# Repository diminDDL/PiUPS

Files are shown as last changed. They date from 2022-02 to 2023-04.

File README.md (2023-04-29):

# The DDL pi UPS


# Terms of use
### The following conditions should be met if you want to use any part of this repository:

By using this project or its parts, for any purpose and in any shape or form, you grant your **implicit agreement** to all the following statements:

- You **condemn Russia and its military aggression against Ukraine**
- You **recognize that Russia is an occupant that unlawfully invaded a sovereign state**
- You **support Ukraine's territorial integrity, including its claims over temporarily occupied territories of Crimea and Donbas**
- You **reject false narratives perpetuated by Russian state propaganda**

To learn more about the war and how you can help, [click here](https://u24.gov.ua/). Glory to Ukraine! 🇺🇦

### AND

## CERN Open Hardware Licence v2 (CERN-OHL-W) TL;DR

- **Can:**
  - *Use*: You are free to use the hardware design in any way.
  - *Modify*: You can make modifications to the design.
  - *Distribute*: You can share the original or modified design with others.
  - *Commercial Use*: You can use the design in commercial projects.

- **Can't:**
  - *Hold Liable*: The original author is not liable for any damages or consequences resulting from the use of the design.

- **Conditions:**
  - *Attribution*: You must give appropriate credit to the original author, including a copyright notice, a link to the license, and an indication of any changes made.
  - *ShareAlike*: If you modify the design, you must distribute your contributions under the same license as the original.
  - *License Notice*: You must include a copy of the CERN-OHL-W v2 with the distributed design or provide a clear link to the license.

Disclaimer: This summary is not a legal document and does not provide legal advice. Please read the full license text for a complete understanding of its terms and conditions.

## Info

This repo contains the hardware and *soon TM* software for the ultra efficient raspberry pi UPS.
The reason this was created was because I wasn't satisfied with the things available on the market
that would just lower the incoming voltage to charge the battery and immediately boost it to power the pi. This way efficiencies of around ~80% can be achieved. Don't get me wrong this is not terrible but I wanted to do better, which is why this design incorporates a power MUX.

### Current revision: 0.5

##### Known issues of rev 0.5

| Issue  | Possible fix |
| --- |:---:|
| Power mux and everything involving the comparator oscilates when trying to shut down. | Use TL431 instead, it combines a voltage reference and a comparator. |
| Turning switch off while plugged in doesn't turn off the output. | Rework the schematic. |
| DW01 chip is acting up (high leakage, not working half of the time). | Replace with BQ2970. |
| BMS turns off when the charger is plugged in. | Try removing diodes going to the fs8205. |

### Pictures
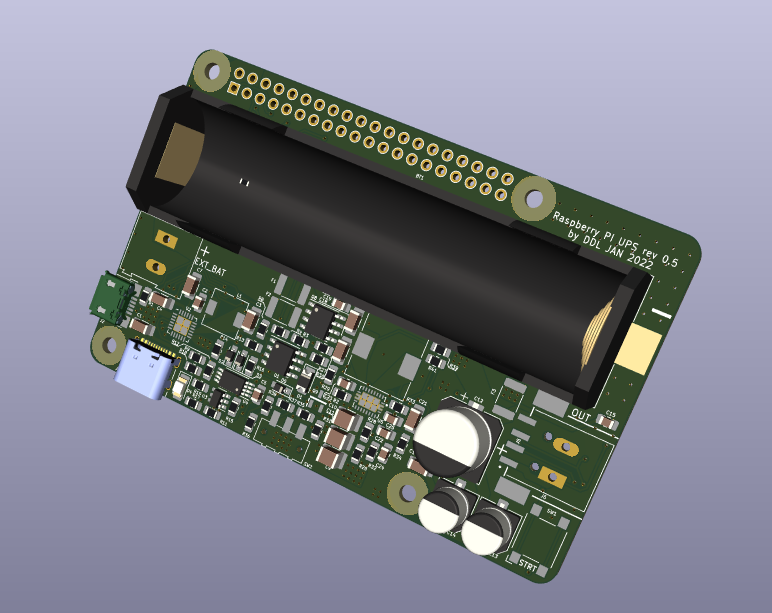
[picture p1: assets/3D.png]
3D render

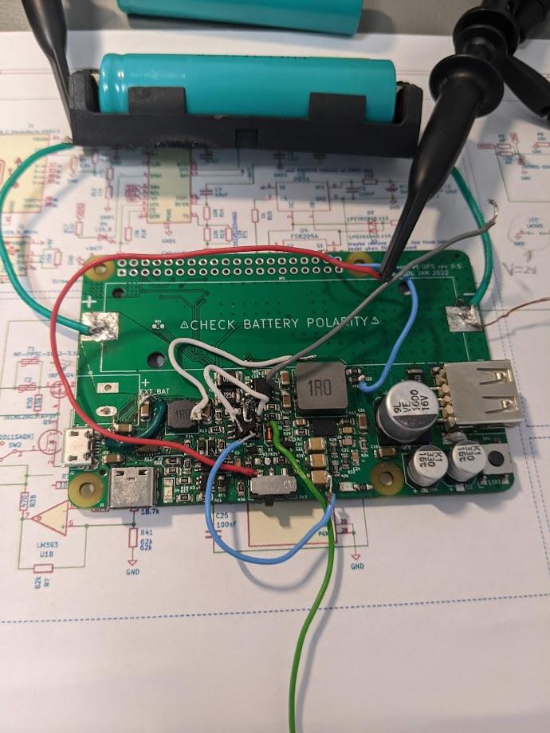
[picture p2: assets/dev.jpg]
Photo in development


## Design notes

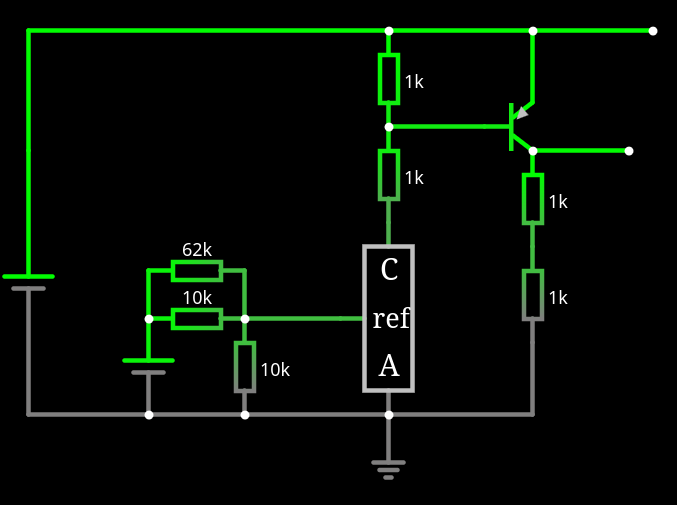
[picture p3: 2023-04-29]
PiUPS/5V_sense_2.png

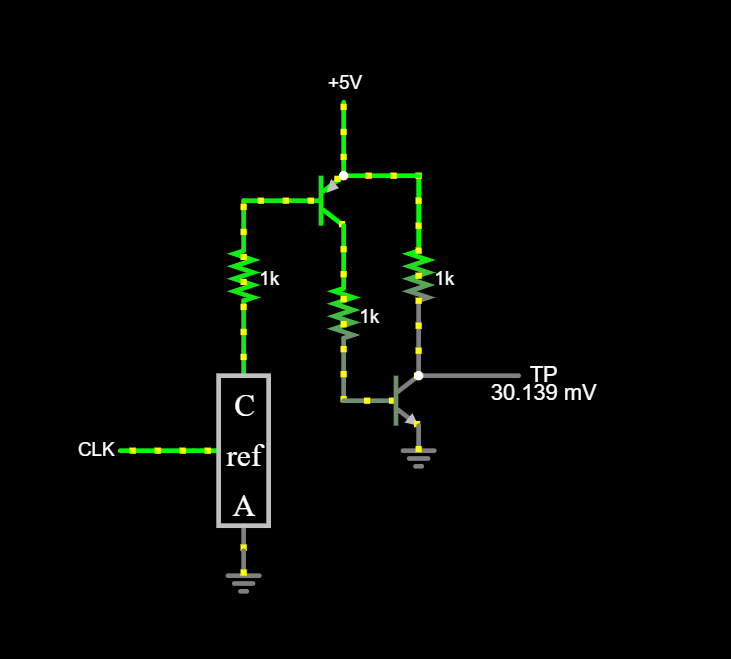
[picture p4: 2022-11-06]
PiUPS/comp_replacement_2.png

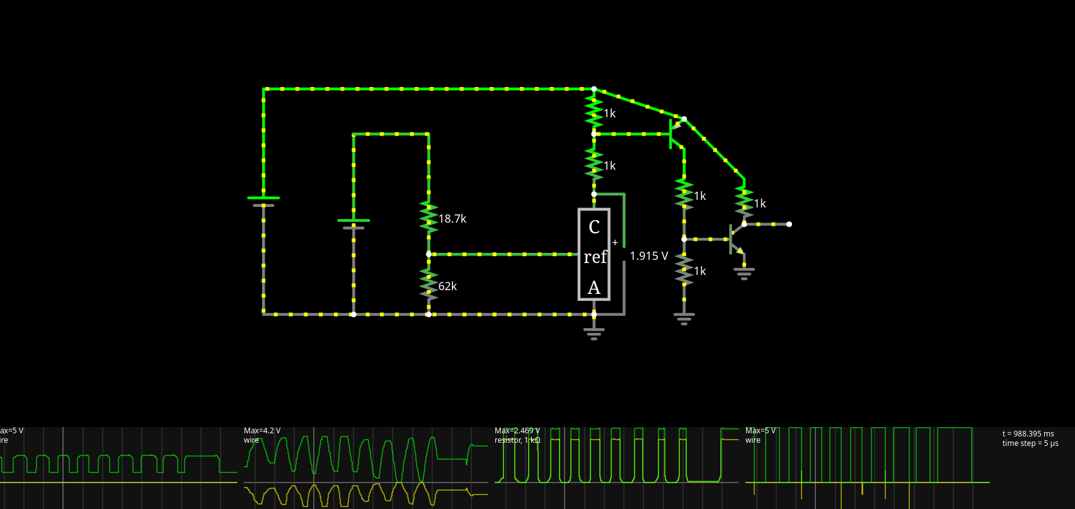
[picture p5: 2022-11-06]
PiUPS/comp_rep.png

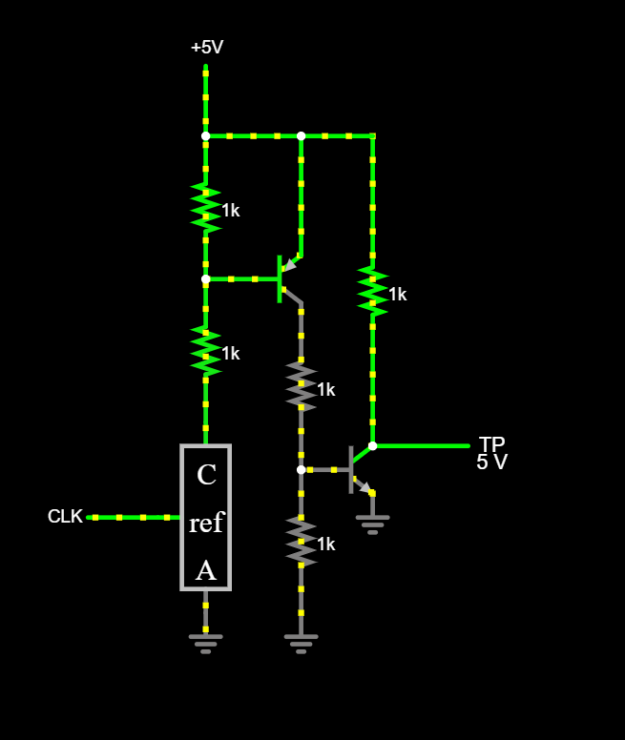
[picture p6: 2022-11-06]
PiUPS/comp_replacement.png

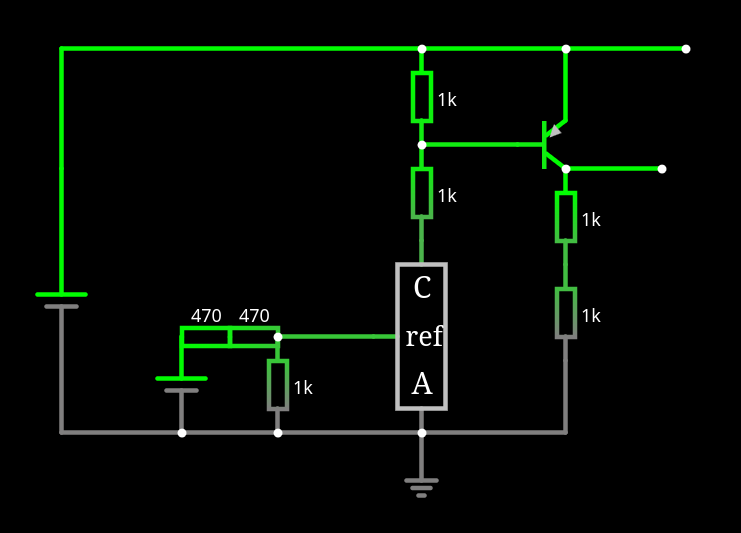
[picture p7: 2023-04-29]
PiUPS/5V_sense.png

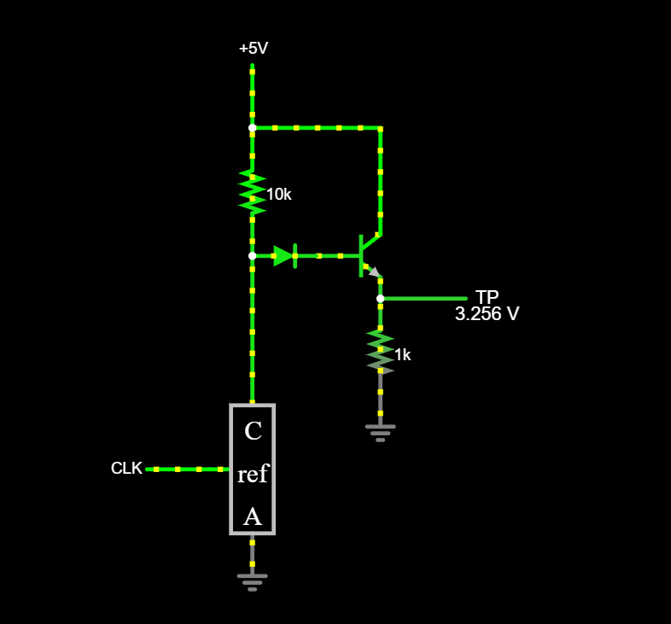
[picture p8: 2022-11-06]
PiUPS/comp_replacement_3.png

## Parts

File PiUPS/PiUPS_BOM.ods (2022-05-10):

Source: | /home/dmytro/Documents/projects/PiUPS/PiUPS/PiUPS.kicad_sch
Date: | Thu May 5 22:53:06 2022 |  |  |  |  |  | key
Tool: | Eeschema 6.0.4-6f826c9f35~116~ubuntu20.04.1 |  |  |  |  |  | DigiKey | Mouser | Both
Generator: | /usr/share/kicad/plugins/bom_csv_grouped_by_value_with_fp.py
Component Count: | 109 |  |  | LCSC
Ref | Qnty | Value | Cmp name | Footprint | Description | Vendor | where? | lcsc
BT1, | 1 | Battery_Cell | Battery_Cell | Battery:BatteryHolder_Keystone_1042_1x18650 | Single-cell battery |  |  | https://lcsc.com/product-detail/Battery-Connectors_MYOUNG-BH-18650-B1BA002_C2988620.html
C1, C3, C4, C6, C7, C16, C21, | 7 | 10uF | C | Capacitor_SMD:C_1206_3216Metric_Pad1.33x1.80mm_HandSolder | Unpolarized capacitor |  |  | https://lcsc.com/product-detail/Multilayer-Ceramic-Capacitors-MLCC-SMD-SMT_FH-Guangdong-Fenghua-Advanced-Tech-1206B106K250NT_C90538.html
C2, C23, | 2 | 47nF | C | Capacitor_SMD:C_0805_2012Metric_Pad1.18x1.45mm_HandSolder | Unpolarized capacitor |  |  | https://lcsc.com/product-detail/Multilayer-Ceramic-Capacitors-MLCC-SMD-SMT_PSA-Prosperity-Dielectrics-FN21X473K500PXG_C525309.html
C5, C8, C15, C17, C19, C25, | 6 | 100nF | C | Capacitor_SMD:C_0805_2012Metric_Pad1.18x1.45mm_HandSolder | Unpolarized capacitor |  |  | https://lcsc.com/product-detail/Multilayer-Ceramic-Capacitors-MLCC-SMD-SMT_TORCH-C0805B104K500NT_C476766.html
C9, C10, C11, | 3 | 47uF | C | Capacitor_SMD:C_1210_3225Metric_Pad1.33x2.70mm_HandSolder | Unpolarized capacitor |  |  | https://lcsc.com/product-detail/Multilayer-Ceramic-Capacitors-MLCC-SMD-SMT_Murata-Electronics-GRM32ER61C476KE15L_C77101.html
C12, | 1 | 1000uF | CP | Capacitor_SMD:CP_Elec_10x10 |  |  |  | https://lcsc.com/product-detail/Aluminum-Electrolytic-Capacitors-SMD_Lelon-VE-102M1CTR-1010_C249474.html
C13, C14, | 2 | 220uF | CP | Capacitor_SMD:CP_Elec_6.3x7.7 |  |  |  | https://lcsc.com/product-detail/Aluminum-Electrolytic-Capacitors-SMD_Lelon-VZT331M1CTR-0607_C882162.html
C18, C20, | 2 | 20uF | C | Capacitor_SMD:C_1206_3216Metric_Pad1.33x1.80mm_HandSolder | Unpolarized capacitor |  |  | https://lcsc.com/product-detail/Multilayer-Ceramic-Capacitors-MLCC-SMD-SMT_Samsung-Electro-Mechanics-CL31A226KOHNNNE_C90146.html
C22, | 1 | 43pF | C | Capacitor_SMD:C_0805_2012Metric_Pad1.18x1.45mm_HandSolder | Unpolarized capacitor |  |  | https://lcsc.com/product-detail/Multilayer-Ceramic-Capacitors-MLCC-SMD-SMT_FH-Guangdong-Fenghua-Advanced-Tech-0805CG430J500NT_C502147.html
C24, | 1 | 1nF | C | Capacitor_SMD:C_0805_2012Metric_Pad1.18x1.45mm_HandSolder | Unpolarized capacitor |  |  | https://lcsc.com/product-detail/Multilayer-Ceramic-Capacitors-MLCC-SMD-SMT_YAGEO-CC0805KRX7R9BB102_C94121.html
D1, | 1 | BZV55-B2V4.115 | D_Zener | Diode_SMD:D_1206_3216Metric_Pad1.42x1.75mm_HandSolder | Zener diode |  |  | https://lcsc.com/product-detail/Zener-Diodes_Nexperia-BZV55-B2V4-115_C550395.html
D2, D3, D5, D6, | 4 | 1PS76SB40.115 | 1N4001 | Diode_SMD:D_SOD-323_HandSoldering | 50V 1A General Purpose Rectifier Diode, DO-41 |  |  | https://lcsc.com/product-detail/Diodes-Fast-Recovery-Rectifiers_YFW-BAV21WS_C2898600.html
D4, | 1 | LED_R | LED | LED_SMD:LED_1206_3216Metric_Pad1.42x1.75mm_HandSolder | Light emitting diode |  |  | https://lcsc.com/product-detail/Light-Emitting-Diodes-LED_XINGLIGHT-XL-3216SURC_C965822.html
F1, F2, | 2 | MF-PPTC-1812-3.5A-6V | Polyfuse | Fuse:Fuse_1812_4532Metric_Pad1.30x3.40mm_HandSolder | Resettable fuse, polymeric positive temperature coefficient |  |  | https://lcsc.com/product-detail/Resettable-Fuses_Shenzhen-JDT-span-style-background-color-ff0-Fuse-span-ASMD1812-350_C135367.html
F3, | 1 | MF-PPTC-1812-2.6A-8V | Polyfuse | Fuse:Fuse_1812_4532Metric_Pad1.30x3.40mm_HandSolder | Resettable fuse, polymeric positive temperature coefficient |  |  | https://lcsc.com/product-detail/Resettable-Fuses_TLC-Electronic-TLC-MSMD250-16_C262033.html
J1, | 1 | USB_C_Receptacle_USB2.0 | USB_C_Receptacle_USB2.0 | Connector_USB:USB_C_Receptacle_Palconn_UTC16-G | USB 2.0-only Type-C Receptacle connector |  |  | https://lcsc.com/product-detail/span-style-background-color-ff0-USB-span-Connectors_Korean-Hroparts-Elec-TYPE-C-31-M-12_C165948.html
J2, | 1 | USB_B_Micro | USB_B_Micro | Connector_USB:USB_Micro-B_Amphenol_10103594-0001LF_Horizontal | USB Micro Type B connector |  |  | https://lcsc.com/product-detail/USB-Connectors_span-style-background-color-ff0-Amphenol-span-ICC-10103594-0001LF_C428495.html
J3, | 1 | Screw_Terminal_01x02 | Screw_Terminal_01x02 | TerminalBlock:TerminalBlock_Altech_AK300-2_P5.00mm | Generic screw terminal, single row, 01x02, script generated (kicad-library-utils/schlib/autogen/connector/) |  |  | https://lcsc.com/product-detail/Screw-terminal_Ningbo-Xinlaiya-Elec-XY300V-A-5-0-2P_C557648.html
J4, | 1 | Raspberry_Pi_2_3 | Raspberry_Pi_2_3 | RPI:raspberrypi_2_3 | expansion header for Raspberry Pi 2 & 3
J5, | 1 | USB_A | USB_A | USB:SAMTEC_USB-A-S-X-X-SM2 | USB Type A connector |  |  | https://lcsc.com/product-detail/span-style-background-color-ff0-USB-span-Connectors_XUNPU-USB-234-BCW_C720528.html
L1, | 1 | 1uH | L | Inductor_SMD:L_6.3x6.3_H3 | Inductor |  |  | https://lcsc.com/product-detail/Power-Inductors_DMBJ-PNLS6028-1R0_C2849518.html
L2, | 1 | 1uH | L | Inductor_SMD:L_10.4x10.4_H4.8 | Inductor |  |  | https://lcsc.com/product-detail/Power-Inductors_MINGSTAR-NBMC1040N-1R0M_C2875677.html
Q1, Q2, Q4, Q5, Q8, | 5 | IRF7404 | IRF7404 | Package_SO:SOIC-8_3.9x4.9mm_P1.27mm | -6.7A Id, -20V Vds, P-Channel HEXFET Power MOSFET, SO-8 |  |  | https://lcsc.com/product-detail/MOSFETs_Infineon-Technologies-IRF7404TRPBF_C2997.html
Q3, Q6, Q7, Q9, | 4 | IRLML2803TRPBF | IRLML2803TRPBF | IRLML2803TRPBF:SOT95P237X112-3N | IRLML2803TRPBF N-Channel MOSFET, 1.2 A, 30 V HEXFET, 3-Pin SOT-23 Infineon |  |  | https://lcsc.com/product-detail/MOSFETs_Infineon-Technologies-IRLML2803TRPBF_C2590.html
R1, R2, R5, R14, R18, R19, R20, R22, R24, R29, R30, R31, R37, R40, R42, R43, | 16 | 10k | R | Resistor_SMD:R_0805_2012Metric_Pad1.20x1.40mm_HandSolder | Resistor |  |  | https://lcsc.com/product-detail/Chip-span-style-background-color-ff0-Resistor-span-Surface-Mount_FH-Guangdong-Fenghua-Advanced-Tech-RS-05K103JT_C115295.html
R3, R4, R8, R9, R10, R12, R13, R16, R23, R25, R27, R35, R36, R38, | 14 | 470 | R | Resistor_SMD:R_0805_2012Metric_Pad1.20x1.40mm_HandSolder | Resistor |  |  | https://lcsc.com/product-detail/Chip-span-style-background-color-ff0-Resistor-span-Surface-Mount_FH-Guangdong-Fenghua-Advanced-Tech-RS-05K471JT_C119076.html
R6, R7, R17, | 3 | 5.1k | R | Resistor_SMD:R_0805_2012Metric_Pad1.20x1.40mm_HandSolder | Resistor |  |  | https://lcsc.com/product-detail/Chip-span-style-background-color-ff0-Resistor-span-Surface-Mount_FH-Guangdong-Fenghua-Advanced-Tech-RS-05K5101FT_C118848.html
R11, | 1 | 100 | R | Resistor_SMD:R_0805_2012Metric_Pad1.20x1.40mm_HandSolder | Resistor |  |  | https://lcsc.com/product-detail/Chip-Resistor-Surface-Mount_FOJAN-FRC0805J101TSD_C2930230.html
R15, | 1 | 1k | R | Resistor_SMD:R_0805_2012Metric_Pad1.20x1.40mm_HandSolder | Resistor |  |  | https://lcsc.com/product-detail/Chip-span-style-background-color-ff0-Resistor-span-Surface-Mount_UNI-ROYAL-Uniroyal-Elec-0805W8J0102T5E_C25623.html
R21, R45, R46, R47, R48, R49, | 6 | USR | R | Resistor_SMD:R_0805_2012Metric_Pad1.20x1.40mm_HandSolder | Resistor
R26, | 1 | 62k | R | Resistor_SMD:R_0805_2012Metric_Pad1.20x1.40mm_HandSolder | Resistor |  |  | https://lcsc.com/product-detail/Chip-span-style-background-color-ff0-Resistor-span-Surface-Mount_LIZ-Elec-CR0805F86202G_C101819.html
R28, | 1 | 200k | R | Resistor_SMD:R_0805_2012Metric_Pad1.20x1.40mm_HandSolder | Resistor |  |  | https://lcsc.com/product-detail/Chip-span-style-background-color-ff0-Resistor-span-Surface-Mount_RALEC-RTT052003FTP_C104082.html
R32, | 1 | 18.7k | R | Resistor_SMD:R_0805_2012Metric_Pad1.20x1.40mm_HandSolder | Resistor |  |  | https://lcsc.com/product-detail/Chip-span-style-background-color-ff0-Resistor-span-Surface-Mount_UNI-ROYAL-Uniroyal-Elec-0805W8F1872T5E_C17499.html
R33, | 1 | 180k | R | Resistor_SMD:R_0805_2012Metric_Pad1.20x1.40mm_HandSolder | Resistor |  |  | https://lcsc.com/product-detail/Chip-span-style-background-color-ff0-Resistor-span-Surface-Mount_UNI-ROYAL-Uniroyal-Elec-0805W8F1803T5E_C17501.html
R34, | 1 | 130k | R | Resistor_SMD:R_0805_2012Metric_Pad1.20x1.40mm_HandSolder | Resistor |  |  | https://lcsc.com/product-detail/Chip-Resistor-Surface-Mount_FOJAN-FRC0805F1303TS_C2933305.html
R39, | 1 | 18k (18.7k) | R | Resistor_SMD:R_0805_2012Metric_Pad1.20x1.40mm_HandSolder | Resistor
R41, | 1 | 200k | R | Resistor_SMD:R_0805_2012Metric_Pad1.20x1.40mm_HandSolder | Resistor |  |  | https://lcsc.com/product-detail/Chip-span-style-background-color-ff0-Resistor-span-Surface-Mount_RALEC-RTT052003FTP_C104082.html
R44, | 1 | 0 | R | Resistor_SMD:R_0805_2012Metric_Pad1.20x1.40mm_HandSolder | Resistor
RT1, | 1 | 10k | R | Resistor_SMD:R_0603_1608Metric | Resistor
SW1, | 1 | SW_MEC_5E | SW_MEC_5E | Button_Switch_SMD:SW_SPST_Omron_B3FS-100xP | MEC 5E single pole normally-open tactile switch |  |  | https://lcsc.com/product-detail/Tactile-Switches_Omron-Electronics-B3FS-1000P_C271750.html
SW2, | 1 | MODE (JS102011SAQN) | SW_SPDT | Button_Switch_SMD:SW_SPDT_CK-JS102011SAQN | Switch, single pole double throw |  |  | https://lcsc.com/product-detail/Slide-Switches_C-K-JS102011SAQN_C221660.html
U1, | 1 | LM393 | LM358 | Package_SO:SOIC-8_3.9x4.9mm_P1.27mm | Low-Power, Dual Operational Amplifiers, DIP-8/SOIC-8/TO-99-8 |  |  | https://lcsc.com/product-detail/Comparators_Texas-Instruments-LM393ADR_C30394.html
U2, | 1 | BQ25895RTW | BQ25895RTW | Package_DFN_QFN:Texas_S-PWQFN-N24_EP2.7x2.7mm_ThermalVias | Controlled Single Cell 5A Fast Charger with MaxCharge, WQFN-24 |  |  | https://lcsc.com/product-detail/Battery-Management-ICs_Texas-Instruments-BQ25895MRTWR_C485917.html
U3, | 1 | DW01 | DW01 | Package_TO_SOT_SMD:SOT-23-6 |  |  |  | https://lcsc.com/product-detail/Battery-Management-ICs_Fortune-Semicon-DW01A-G_C61503.html
U4, | 1 | FS8205A | FS8205A | Package_SO:TSSOP-8_4.4x3mm_P0.65mm |  |  |  | https://lcsc.com/product-detail/MOSFETs_Fortune-Semicon-FS8205A_C16052.html
U5, | 1 | TPS61088RHLR | TPS61088RHLR | tps61088:IC_TPS61088RHLR |  |  |  | https://lcsc.com/product-detail/DC-DC-Converters_Texas-Instruments-TPS61088RHLR_C87357.html
U6, | 1 | DS3231M | DS3231M | Package_SO:SOIC-16W_7.5x10.3mm_P1.27mm | Extremely Accurate I2C-Integrated RTC/TCXO/Crystal SOIC-16 |  |  | https://lcsc.com/product-detail/Real-time-Clocks-RTC_Maxim-Integrated-DS3231M-TRL_C37663.html

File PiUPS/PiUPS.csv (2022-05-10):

Source: | /home/dmytro/Documents/projects/PiUPS/PiUPS/PiUPS.kicad_sch
Date: | Thu May 5 22:53:06 2022
Tool: | Eeschema 6.0.4-6f826c9f35~116~ubuntu20.04.1
Generator: | /usr/share/kicad/plugins/bom_csv_grouped_by_value_with_fp.py
Component Count: | 109
Ref | Qnty | Value | Cmp name | Footprint | Description | Vendor
BT1, | 1 | Battery_Cell | Battery_Cell | Battery:BatteryHolder_Keystone_1042_1x18650 | Single-cell battery
C1, C3, C4, C6, C7, C16, C21, | 7 | 10uF | C | Capacitor_SMD:C_1206_3216Metric_Pad1.33x1.80mm_HandSolder | Unpolarized capacitor
C2, C23, | 2 | 47nF | C | Capacitor_SMD:C_0805_2012Metric_Pad1.18x1.45mm_HandSolder | Unpolarized capacitor
C5, C8, C15, C17, C19, C25, | 6 | 100nF | C | Capacitor_SMD:C_0805_2012Metric_Pad1.18x1.45mm_HandSolder | Unpolarized capacitor
C9, C10, C11, | 3 | 47uF | C | Capacitor_SMD:C_1210_3225Metric_Pad1.33x2.70mm_HandSolder | Unpolarized capacitor
C12, | 1 | 1000uF | CP | Capacitor_SMD:CP_Elec_10x10
C13, C14, | 2 | 220uF | CP | Capacitor_SMD:CP_Elec_6.3x7.7
C18, C20, | 2 | 20uF | C | Capacitor_SMD:C_1206_3216Metric_Pad1.33x1.80mm_HandSolder | Unpolarized capacitor
C22, | 1 | 43pF | C | Capacitor_SMD:C_0805_2012Metric_Pad1.18x1.45mm_HandSolder | Unpolarized capacitor
C24, | 1 | 1nF | C | Capacitor_SMD:C_0805_2012Metric_Pad1.18x1.45mm_HandSolder | Unpolarized capacitor
D1, | 1 | BZV55-B2V4.115 | D_Zener | Diode_SMD:D_1206_3216Metric_Pad1.42x1.75mm_HandSolder | Zener diode
D2, D3, D5, D6, | 4 | 1PS76SB40.115 | 1N4001 | Diode_SMD:D_SOD-323_HandSoldering | 50V 1A General Purpose Rectifier Diode, DO-41
D4, | 1 | LED_R | LED | LED_SMD:LED_1206_3216Metric_Pad1.42x1.75mm_HandSolder | Light emitting diode
F1, F2, | 2 | MF-PPTC-1812-3.5A-6V | Polyfuse | Fuse:Fuse_1812_4532Metric_Pad1.30x3.40mm_HandSolder | Resettable fuse, polymeric positive temperature coefficient
F3, | 1 | MF-PPTC-1812-2.6A-8V | Polyfuse | Fuse:Fuse_1812_4532Metric_Pad1.30x3.40mm_HandSolder | Resettable fuse, polymeric positive temperature coefficient
J1, | 1 | USB_C_Receptacle_USB2.0 | USB_C_Receptacle_USB2.0 | Connector_USB:USB_C_Receptacle_Palconn_UTC16-G | USB 2.0-only Type-C Receptacle connector
J2, | 1 | USB_B_Micro | USB_B_Micro | Connector_USB:USB_Micro-B_Amphenol_10103594-0001LF_Horizontal | USB Micro Type B connector
J3, | 1 | Screw_Terminal_01x02 | Screw_Terminal_01x02 | TerminalBlock:TerminalBlock_Altech_AK300-2_P5.00mm | Generic screw terminal, single row, 01x02, script generated (kicad-library-utils/schlib/autogen/connector/)
J4, | 1 | Raspberry_Pi_2_3 | Raspberry_Pi_2_3 | RPI:raspberrypi_2_3 | expansion header for Raspberry Pi 2 & 3
J5, | 1 | USB_A | USB_A | USB:SAMTEC_USB-A-S-X-X-SM2 | USB Type A connector
L1, | 1 | 1uH | L | Inductor_SMD:L_6.3x6.3_H3 | Inductor
L2, | 1 | 1uH | L | Inductor_SMD:L_10.4x10.4_H4.8 | Inductor
Q1, Q2, Q4, Q5, Q8, | 5 | IRF7404 | IRF7404 | Package_SO:SOIC-8_3.9x4.9mm_P1.27mm | -6.7A Id, -20V Vds, P-Channel HEXFET Power MOSFET, SO-8
Q3, Q6, Q7, Q9, | 4 | IRLML2803TRPBF | IRLML2803TRPBF | IRLML2803TRPBF:SOT95P237X112-3N | IRLML2803TRPBF N-Channel MOSFET, 1.2 A, 30 V HEXFET, 3-Pin SOT-23 Infineon
R1, R2, R5, R14, R18, R19, R20, R22, R24, R29, R30, R31, R37, R40, R42, R43, | 16 | 10k | R | Resistor_SMD:R_0805_2012Metric_Pad1.20x1.40mm_HandSolder | Resistor
R3, R4, R8, R9, R10, R12, R13, R16, R23, R25, R27, R35, R36, R38, | 14 | 470 | R | Resistor_SMD:R_0805_2012Metric_Pad1.20x1.40mm_HandSolder | Resistor
R6, R7, R17, | 3 | 5.1k | R | Resistor_SMD:R_0805_2012Metric_Pad1.20x1.40mm_HandSolder | Resistor
R11, | 1 | 100 | R | Resistor_SMD:R_0805_2012Metric_Pad1.20x1.40mm_HandSolder | Resistor
R15, | 1 | 1k | R | Resistor_SMD:R_0805_2012Metric_Pad1.20x1.40mm_HandSolder | Resistor
R21, R45, R46, R47, R48, R49, | 6 | USR | R | Resistor_SMD:R_0805_2012Metric_Pad1.20x1.40mm_HandSolder | Resistor
R26, | 1 | 64.9k | R | Resistor_SMD:R_0805_2012Metric_Pad1.20x1.40mm_HandSolder | Resistor
R28, | 1 | 210k | R | Resistor_SMD:R_0805_2012Metric_Pad1.20x1.40mm_HandSolder | Resistor
R32, | 1 | 18.7k | R | Resistor_SMD:R_0805_2012Metric_Pad1.20x1.40mm_HandSolder | Resistor
R33, | 1 | 174k | R | Resistor_SMD:R_0805_2012Metric_Pad1.20x1.40mm_HandSolder | Resistor
R34, | 1 | 147k | R | Resistor_SMD:R_0805_2012Metric_Pad1.20x1.40mm_HandSolder | Resistor
R39, | 1 | 18k | R | Resistor_SMD:R_0805_2012Metric_Pad1.20x1.40mm_HandSolder | Resistor
R41, | 1 | 200k | R | Resistor_SMD:R_0805_2012Metric_Pad1.20x1.40mm_HandSolder | Resistor
R44, | 1 | 0 | R | Resistor_SMD:R_0805_2012Metric_Pad1.20x1.40mm_HandSolder | Resistor
RT1, | 1 | 10k | R | Resistor_SMD:R_0603_1608Metric | Resistor
SW1, | 1 | SW_MEC_5E | SW_MEC_5E | Button_Switch_SMD:SW_SPST_Omron_B3FS-100xP | MEC 5E single pole normally-open tactile switch
SW2, | 1 | MODE (JS102011SAQN) | SW_SPDT | Button_Switch_SMD:SW_SPDT_CK-JS102011SAQN | Switch, single pole double throw
U1, | 1 | LM393 | LM358 | Package_SO:SOIC-8_3.9x4.9mm_P1.27mm | Low-Power, Dual Operational Amplifiers, DIP-8/SOIC-8/TO-99-8
U2, | 1 | BQ25895RTW | BQ25895RTW | Package_DFN_QFN:Texas_S-PWQFN-N24_EP2.7x2.7mm_ThermalVias | Controlled Single Cell 5A Fast Charger with MaxCharge, WQFN-24
U3, | 1 | DW01 | DW01 | Package_TO_SOT_SMD:SOT-23-6
U4, | 1 | FS8205A | FS8205A | Package_SO:TSSOP-8_4.4x3mm_P0.65mm
U5, | 1 | TPS61088RHLR | TPS61088RHLR | tps61088:IC_TPS61088RHLR
U6, | 1 | DS3231M | DS3231M | Package_SO:SOIC-16W_7.5x10.3mm_P1.27mm | Extremely Accurate I2C-Integrated RTC/TCXO/Crystal SOIC-16

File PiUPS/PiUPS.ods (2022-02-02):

Source: | /home/dima/Documents/kicad/SimplePiUPS/PiUPS/PiUPS.sch |  |  |  |  |  |  |  |  | Total BOM cost:
Date: | Sat Aug 14 00:54:20 2021 |  |  |  |  |  |  |  |  | $21.68 | USD
Tool: | Eeschema 5.1.10-88a1d61d58~90~ubuntu20.04.1
Generator: | /usr/share/kicad/plugins/bom_csv_grouped_by_value_with_fp.py
Component Count: | 93
Ref | Qnty | Value | Cmp name | Footprint | Description | Done | price for all: | price per unit: | link | Opt
BT1, | 1 | Battery_Cell | Battery_Cell | Battery:BatteryHolder_Keystone_1042_1x18650 | Single-cell battery | _ | $0.43 | $0.43 | https://www.aliexpress.com/item/4001152338150.html?spm=a2g0o.cart.0.0.2d383c00oRo9iD&mp=1
C1, | 1 | 47nF | C | Capacitor_SMD:C_0805_2012Metric_Pad1.18x1.45mm_HandSolder | Unpolarized capacitor | _ | $0.01 | $0.01 | https://lcsc.com/product-detail/Multilayer-Ceramic-Capacitors-MLCC-SMD-SMT_PSA-Prosperity-Dielectrics-FN21X473K500PXG_C525309.html
C2, C3, C4, C12, C13, C15, C18, C25, | 8 | 10uF | C | Capacitor_SMD:C_1206_3216Metric_Pad1.33x1.80mm_HandSolder | Unpolarized capacitor | _ | $0.42 | $0.05 | https://lcsc.com/product-detail/Multilayer-Ceramic-Capacitors-MLCC-SMD-SMT_FH-Guangdong-Fenghua-Advanced-Tech-1206B106K250NT_C90538.html
C5, C6, C7, | 3 | 47uF | C | Capacitor_SMD:C_1210_3225Metric_Pad1.33x2.70mm_HandSolder | Unpolarized capacitor | _ | $0.58 | $0.19 | https://lcsc.com/product-detail/Multilayer-Ceramic-Capacitors-MLCC-SMD-SMT_Murata-Electronics-GRM32ER61C476KE15L_C77101.html
C8, C10, C19, C20, C24, | 5 | 100nF | C | Capacitor_SMD:C_0805_2012Metric_Pad1.18x1.45mm_HandSolder | Unpolarized capacitor | _ | $0.03 | $0.01 | https://lcsc.com/product-detail/Multilayer-Ceramic-Capacitors-MLCC-SMD-SMT_TORCH-C0805B104K500NT_C476766.html
C9, C11, | 2 | 20uF | C | Capacitor_SMD:C_1206_3216Metric_Pad1.33x1.80mm_HandSolder | Unpolarized capacitor | (22u) | $0.10 | $0.05 | https://lcsc.com/product-detail/Multilayer-Ceramic-Capacitors-MLCC-SMD-SMT_Samsung-Electro-Mechanics-CL31A226KOHNNNE_C90146.html
C14, | 1 | 43pF | C | Capacitor_SMD:C_0805_2012Metric_Pad1.18x1.45mm_HandSolder | Unpolarized capacitor | _ | $0.01 | $0.01 | https://lcsc.com/product-detail/Multilayer-Ceramic-Capacitors-MLCC-SMD-SMT_FH-Guangdong-Fenghua-Advanced-Tech-0805CG430J500NT_C502147.html
C16, | 1 | 8.2nF | C | Capacitor_SMD:C_0805_2012Metric_Pad1.18x1.45mm_HandSolder | Unpolarized capacitor | _ | $0.01 | $0.01 | https://lcsc.com/product-detail/Multilayer-Ceramic-Capacitors-MLCC-SMD-SMT_FH-Guangdong-Fenghua-Advanced-Tech-0805B822K500NT_C1758.html
C17, | 1 | 1nF | C | Capacitor_SMD:C_0805_2012Metric_Pad1.18x1.45mm_HandSolder | Unpolarized capacitor | _ | $0.01 | $0.01 | https://lcsc.com/product-detail/Multilayer-Ceramic-Capacitors-MLCC-SMD-SMT_YAGEO-CC0805KRX7R9BB102_C94121.html
C21, | 1 | 220uF | CP | Capacitor_SMD:CP_Elec_10x10 | Polarized capacitor | _ | $0.00
C22, C23, | 2 | 220uF | CP | Capacitor_SMD:CP_Elec_6.3x7.7 | Polarized capacitor | _ | $0.00
D1, | 1 | BZV55-B2V4.115 | D_Zener | Diode_SMD:D_1206_3216Metric_Pad1.42x1.75mm_HandSolder | Zener diode | _ | $0.08 | $0.08 | https://lcsc.com/product-detail/Zener-Diodes_Nexperia-BZV55-B2V4-115_C550395.html
D2, | 1 | LED_R | LED | LED_SMD:LED_0805_2012Metric | Light emitting diode | X | $0.04 | $0.04 | https://lcsc.com/product-detail/Light-Emitting-Diodes-span-style-background-color-ff0-LED-span_Everlight-Elec-17-215SURC-S530-A2-TR8_C142306.html
D3, | 1 | LED_G | LED | LED_SMD:LED_0805_2012Metric | Light emitting diode | X | $0.05 | $0.05 | https://lcsc.com/product-detail/Light-Emitting-Diodes-span-style-background-color-ff0-LED-span_Lite-On-LTST-C170TGKT_C364562.html
D4, | 1 | 1N4001 | 1N4001 | SOD-123FL | 50V 1A General Purpose Rectifier Diode, DO-41 | X | $0.01 | $0.01 | https://lcsc.com/product-detail/Diodes-General-Purpose_Shandong-Jingdao-Microelectronics-1N4007W_C108803.html
F1, F2, | 2 | MF-PPTC-1812-3.5A-6V | Polyfuse | Fuse:Fuse_1812_4532Metric_Pad1.30x3.40mm_HandSolder | Resettable fuse, polymeric positive temperature coefficient | _ | $0.23 | $0.12 | https://lcsc.com/product-detail/Resettable-Fuses_Shenzhen-JDT-span-style-background-color-ff0-Fuse-span-ASMD1812-350_C135367.html
F3, | 1 | MF-PPTC-1812-2.6A-8V | Polyfuse | Fuse:Fuse_1812_4532Metric_Pad1.30x3.40mm_HandSolder | Resettable fuse, polymeric positive temperature coefficient | _ | $0.09 | $0.09 | https://lcsc.com/product-detail/Resettable-Fuses_Shenzhen-JDT-span-style-background-color-ff0-Fuse-span-ASMD1812-260_C135365.html
J1, | 1 | USB_C_Receptacle_USB2.0 | USB_C_Receptacle_USB2.0 | Connector_USB:USB_C_Receptacle_Palconn_UTC16-G | USB 2.0-only Type-C Receptacle connector | _ | $0.32 | $0.32 | https://lcsc.com/product-detail/span-style-background-color-ff0-USB-span-Connectors_Korean-Hroparts-Elec-TYPE-C-31-M-12_C165948.html
J2, | 1 | Raspberry_Pi_2_3 | Raspberry_Pi_2_3 | RPI:raspberrypi_2_3 | expansion header for Raspberry Pi 2 & 3 | _ | $1.06 | $1.06 | https://lcsc.com/product-detail/Female-Headers_BOOMELE-Boom-Precision-Elec-C35165_C35165.html
J3, | 1 | USB_A | USB_A | Connector_USB:USB_A_Stewart_SS-52100-001_Horizontal | USB Type A connector | _ | $0.04 | $0.04 | https://lcsc.com/product-detail/span-style-background-color-ff0-USB-span-Connectors_SHOU-HAN-AF180QT1-0_C404963.html
J4, | 1 | USB_B_Micro | USB_B_Micro | Connector_USB:USB_Micro-B_GCT_USB3076-30-A | USB Micro Type B connector | _ | $0.12 | $0.12 | https://lcsc.com/product-detail/USB-Connectors_span-style-background-color-ff0-Amphenol-span-ICC-10103594-0001LF_C428495.html
J5, J6, | 2 | Screw_Terminal_01x02 | Screw_Terminal_01x02 | TerminalBlock:TerminalBlock_Altech_AK300-2_P5.00mm | Generic screw terminal, single row, 01x02, script generated (kicad-library-utils/schlib/autogen/connector/) | _ | $1.62 | $0.81 | https://lcsc.com/product-detail/Screw-terminal_METZ-CONNECT-GmbH-31001102_C123210.html
L1, L2, | 2 | 1uH | L | Inductor_SMD:L_10.4x10.4_H4.8 | Inductor | _ | $0.36 | $0.18 | https://lcsc.com/product-detail/Power-Inductors_Cyntec-PCMB104T-1R0MT_C218791.html
Q1, Q2, Q4, Q5, | 4 | IRF7404 | IRF7404 | Package_SO:SOIC-8_3.9x4.9mm_P1.27mm | -6.7A Id, -20V Vds, P-Channel HEXFET Power MOSFET, SO-8 | _ | $2.98 | $0.74 | https://lcsc.com/product-detail/MOSFETs_Infineon-Technologies-IRF7404TRPBF_C2997.html
Q3, Q6, Q7, | 3 | IRLML2803TRPBF | IRLML2803TRPBF | IRLML2803TRPBF:SOT95P237X112-3N | IRLML2803TRPBF N-Channel MOSFET, 1.2 A, 30 V HEXFET, 3-Pin SOT-23 Infineon | X | $0.60 | $0.20 | https://lcsc.com/product-detail/MOSFETs_Infineon-Technologies-IRLML2803TRPBF_C2590.html
R1, | 1 | 64.9k | R | Resistor_SMD:R_0805_2012Metric_Pad1.20x1.40mm_HandSolder | Resistor | (62k) | $0.00 | $0.00 | https://lcsc.com/product-detail/Chip-span-style-background-color-ff0-Resistor-span-Surface-Mount_LIZ-Elec-CR0805F86202G_C101819.html
R2, R3, R4, R6, R8, R10, R18, R22, R28, R29, R30, R31, R33, R34, R36, R39, | 16 | 10k | R | Resistor_SMD:R_0805_2012Metric_Pad1.20x1.40mm_HandSolder | Resistor | _ | $0.02 | $0.00 | https://lcsc.com/product-detail/Chip-span-style-background-color-ff0-Resistor-span-Surface-Mount_FH-Guangdong-Fenghua-Advanced-Tech-RS-05K103JT_C115295.html
R5, | 1 | 210k | R | Resistor_SMD:R_0805_2012Metric_Pad1.20x1.40mm_HandSolder | Resistor | (200k) | $0.00 | $0.00 | https://lcsc.com/product-detail/Chip-span-style-background-color-ff0-Resistor-span-Surface-Mount_RALEC-RTT052003FTP_C104082.html
R7, | 1 | 1k | R | Resistor_SMD:R_0805_2012Metric_Pad1.20x1.40mm_HandSolder | Resistor | _ | $0.00 | $0.00 | https://lcsc.com/product-detail/Chip-span-style-background-color-ff0-Resistor-span-Surface-Mount_UNI-ROYAL-Uniroyal-Elec-0805W8J0102T5E_C25623.html
R9, R11, R13, R15, | 4 | 5.1k | R | Resistor_SMD:R_0805_2012Metric_Pad1.20x1.40mm_HandSolder | Resistor | _ | $0.01 | $0.00 | https://lcsc.com/product-detail/Chip-span-style-background-color-ff0-Resistor-span-Surface-Mount_FH-Guangdong-Fenghua-Advanced-Tech-RS-05K5101FT_C118848.html
R12, | 1 | 0 | R | Resistor_SMD:R_0805_2012Metric_Pad1.20x1.40mm_HandSolder | Resistor | _ | $0.00 | $0.00 | https://lcsc.com/product-detail/Chip-span-style-background-color-ff0-Resistor-span-Surface-Mount_UNI-ROYAL-Uniroyal-Elec-0805W8J0000T5E_C25275.html
R14, R23, R35, R37, R38, | 5 | 470 | R | Resistor_SMD:R_0805_2012Metric_Pad1.20x1.40mm_HandSolder | Resistor | _ | $0.01 | $0.00 | https://lcsc.com/product-detail/Chip-span-style-background-color-ff0-Resistor-span-Surface-Mount_FH-Guangdong-Fenghua-Advanced-Tech-RS-05K471JT_C119076.html
R16, R17, R19, R20, R21, R26, R32, | 7 | USR | R | Resistor_SMD:R_0805_2012Metric_Pad1.20x1.40mm_HandSolder | Resistor |  | $0.00
R24, | 1 | 18.7k | R | Resistor_SMD:R_0805_2012Metric_Pad1.20x1.40mm_HandSolder | Resistor | - | $0.00 | $0.00 | https://lcsc.com/product-detail/Chip-span-style-background-color-ff0-Resistor-span-Surface-Mount_UNI-ROYAL-Uniroyal-Elec-0805W8F1872T5E_C17499.html
R25, | 1 | 174k | R | Resistor_SMD:R_0805_2012Metric_Pad1.20x1.40mm_HandSolder | Resistor | (180k) | $0.00 | $0.00 | https://lcsc.com/product-detail/Chip-span-style-background-color-ff0-Resistor-span-Surface-Mount_UNI-ROYAL-Uniroyal-Elec-0805W8F1803T5E_C17501.html
R27, | 1 | 147k | R | Resistor_SMD:R_0805_2012Metric_Pad1.20x1.40mm_HandSolder | Resistor | (130k) | $0.00 | $0.00 | https://lcsc.com/product-detail/Chip-span-style-background-color-ff0-Resistor-span-Surface-Mount_HKR-Hong-Kong-Resistors-RCT05130KFLF_C178217.html
SW1, | 1 | MODE (JS102011SAQN) | SW_SPDT | Button_Switch_SMD:SW_SPDT_CK-JS102011SAQN | Switch, single pole double throw | _ | $0.76 | $0.76 | https://lcsc.com/product-detail/Slide-Switches_C-K-JS102011SAQN_C221660.html
SW2, | 1 | SW_MEC_5E | SW_MEC_5E | Button_Switch_SMD:SW_SPST_Omron_B3FS-100xP | MEC 5E single pole normally-open tactile switch | X | $0.00
U1, | 1 | LM393 | LM393 | Package_SO:SOIC-8_3.9x4.9mm_P1.27mm | Low-Power, Dual Operational Amplifiers, DIP-8/SOIC-8/TO-99-8 | _ | $0.21 | $0.21 | https://lcsc.com/product-detail/Comparators_Texas-Instruments-LM393ADR_C30394.html
U2, | 1 | BQ25601 | BQ25601 | Package_DFN_QFN:Texas_S-PWQFN-N24_EP2.7x2.7mm_ThermalVias | I2C Controlled 3A Single-Cell Battery Charger for High Input Voltage and Narrow Voltage DC Power Path Management, WQFN-32 | _ | $1.89 | $1.89 | https://lcsc.com/product-detail/Battery-Management-ICs_Texas-Instruments-BQ25601RTWR_C468236.html
U3, | 1 | TPS61088RHLR | TPS61088RHLR | tps61088:IC_TPS61088RHLR |  | X | $4.37 | $4.37 | https://lcsc.com/product-detail/DC-DC-Converters_Texas-Instruments-TPS61088RHLR_C87357.html
U4, | 1 | DS3231M | DS3231M | Package_SO:SOIC-16W_7.5x10.3mm_P1.27mm | Extremely Accurate I2C-Integrated RTC/TCXO/Crystal SOIC-16 | X | $4.42 | $4.42 | https://lcsc.com/product-detail/Real-time-Clocks-RTC_Maxim-Integrated-DS3231M-TRL_C37663.html | 1
PCB | 1 |  |  |  |  |  | $0.80
 |  |  |  |  |  |  |  |  | https://lcsc.com/product-detail/Power-Inductors_Vishay-Intertech-IHLP2525CZER1R0M01_C845018.html

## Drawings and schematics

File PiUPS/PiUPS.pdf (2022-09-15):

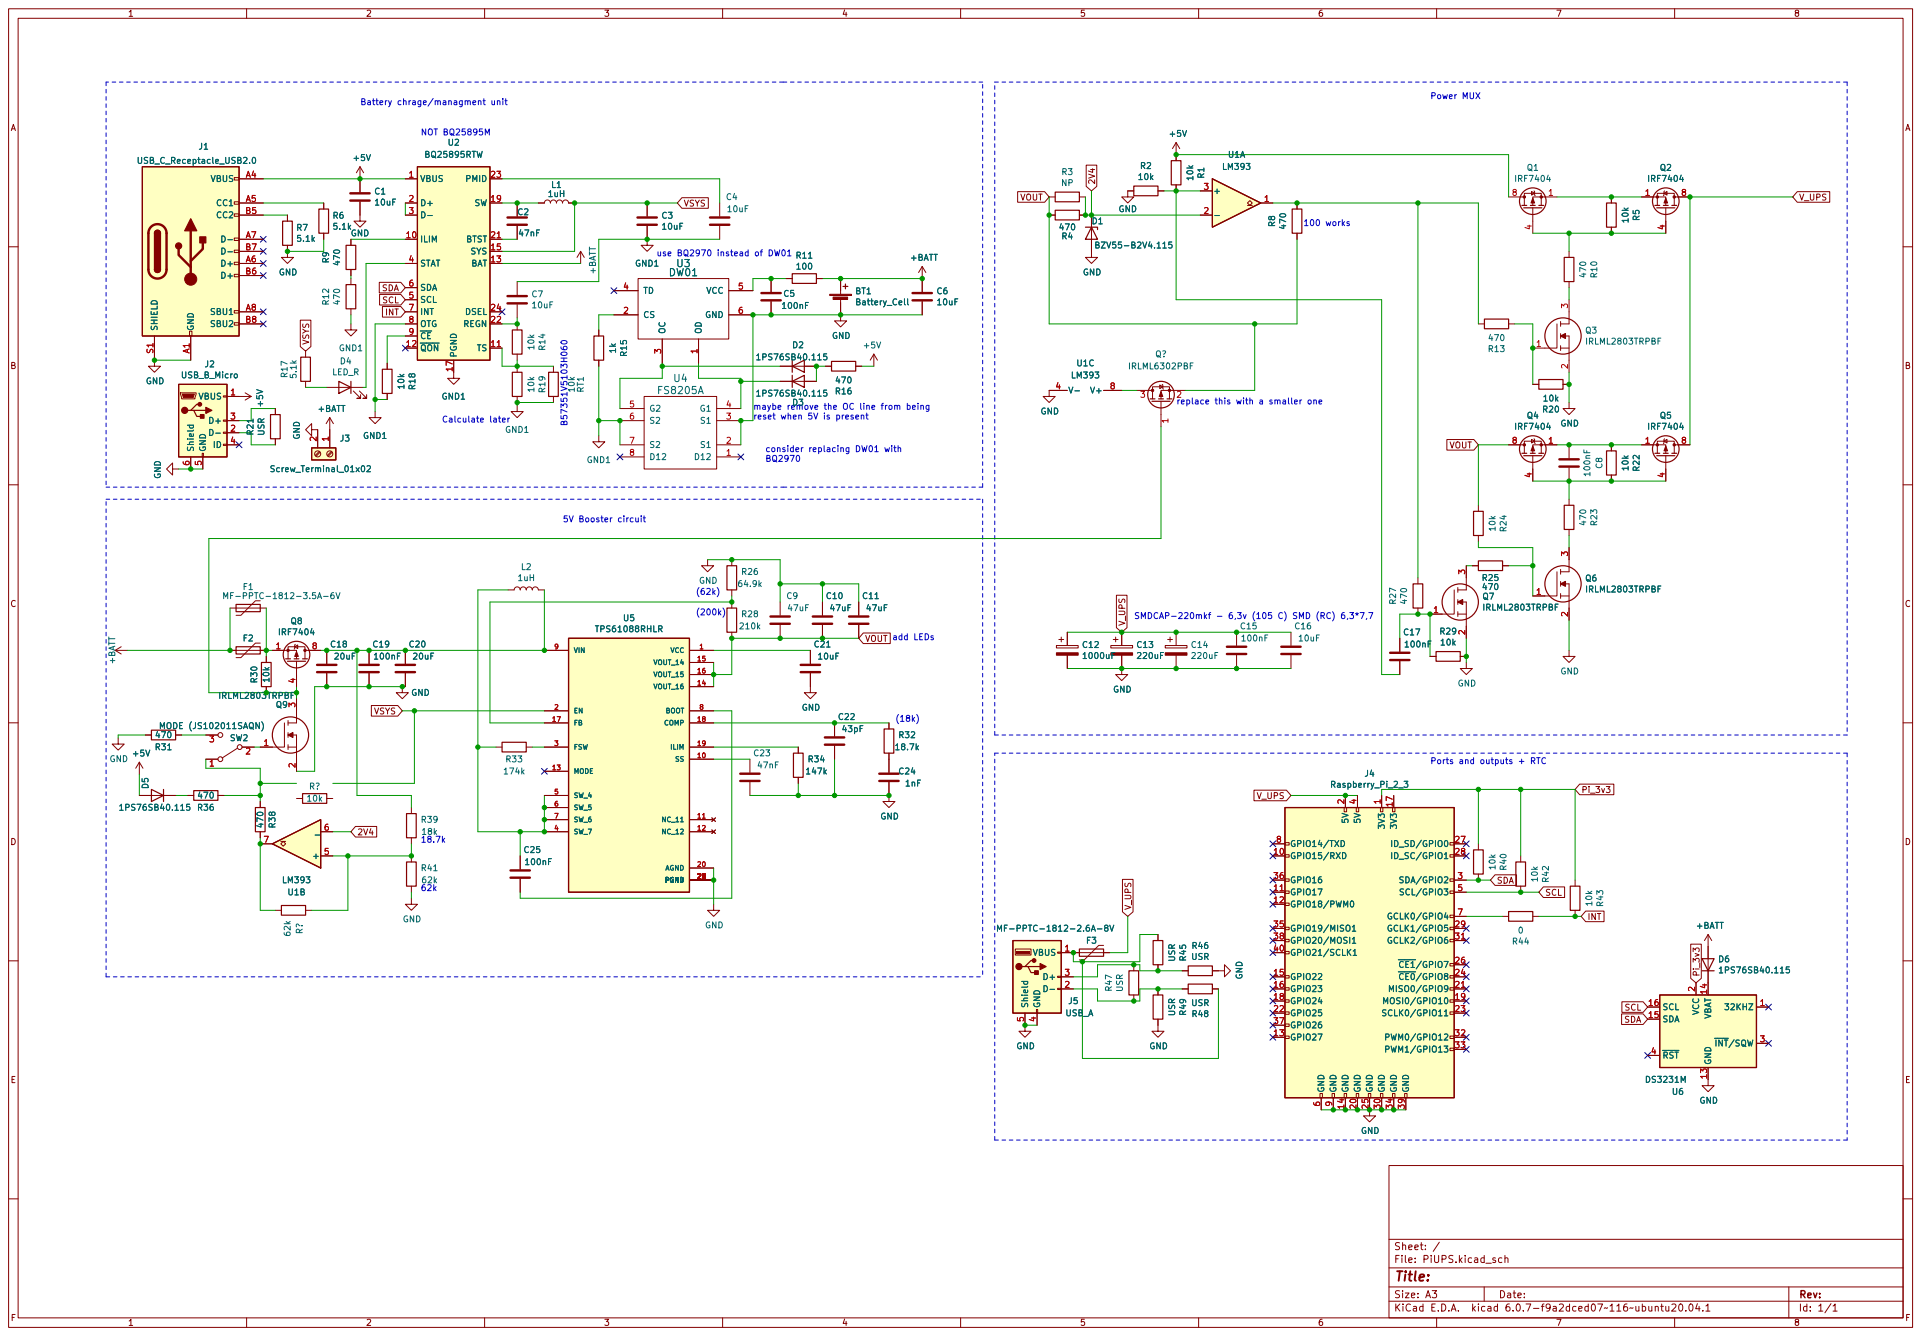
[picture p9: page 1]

replace this with a smaller one

reset when 5V is present 5V Booster circuit

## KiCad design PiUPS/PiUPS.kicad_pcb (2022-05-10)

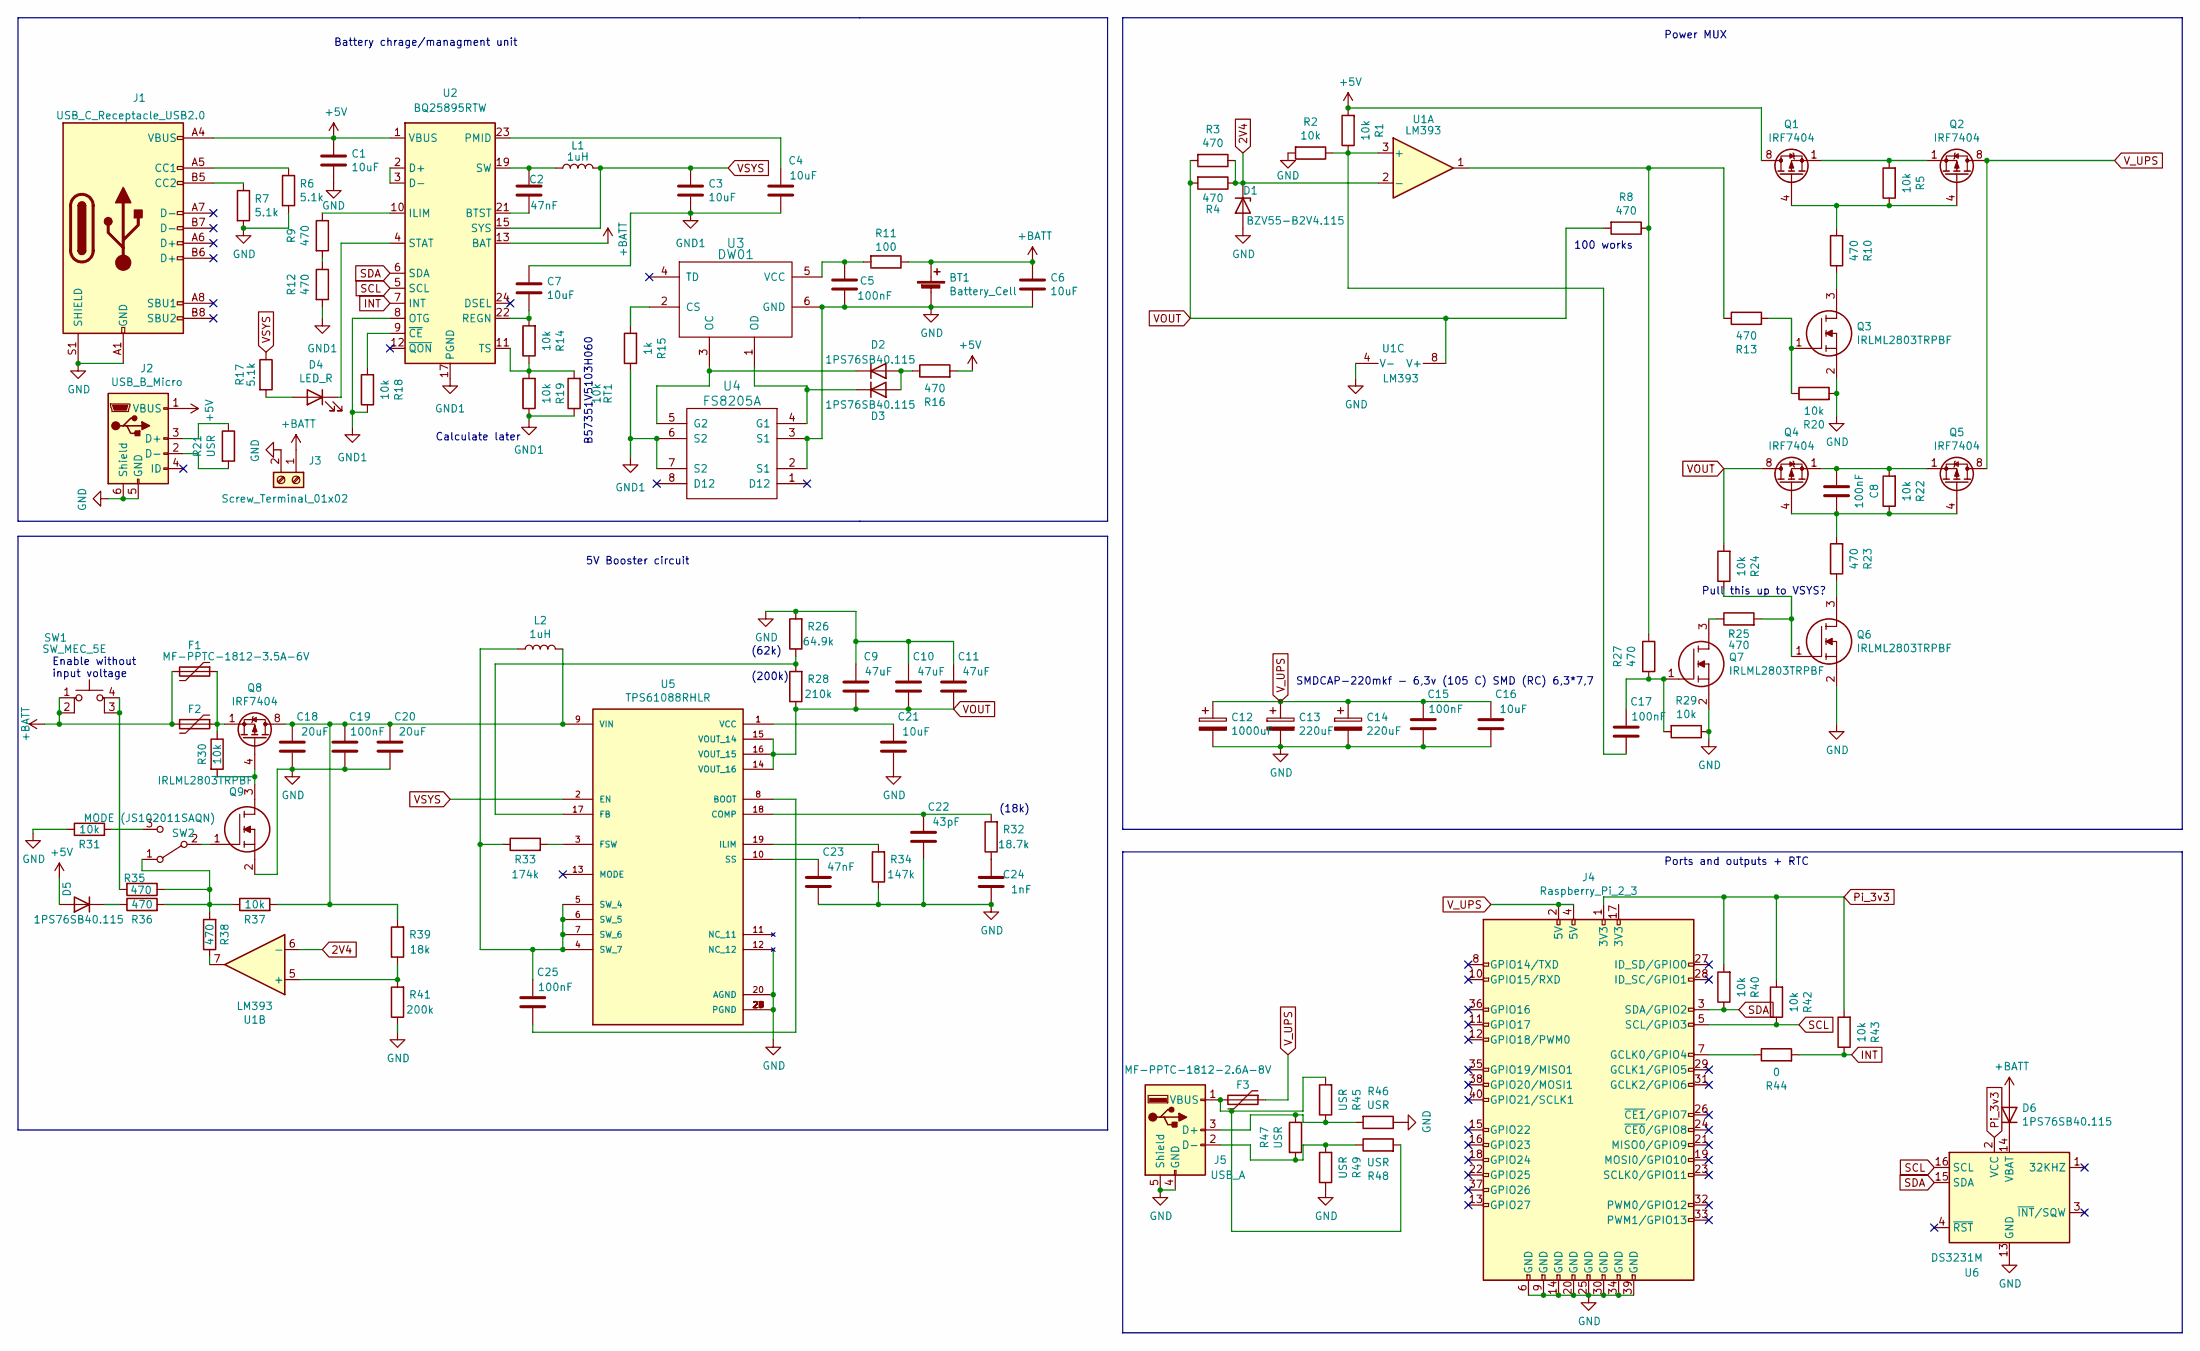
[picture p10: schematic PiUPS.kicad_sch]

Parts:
BT1: Battery_Cell; BatteryHolder_Keystone_1042_1x18650
C1, C3, C4, C6, C7, C16, C21: 10uF; C_1206_3216Metric_Pad1.33x1.80mm_HandSolder
C2, C23: 47nF; C_0805_2012Metric_Pad1.18x1.45mm_HandSolder
C5, C8, C15, C17, C19, C25: 100nF; C_0805_2012Metric_Pad1.18x1.45mm_HandSolder
C9, C10, C11: 47uF; C_1210_3225Metric_Pad1.33x2.70mm_HandSolder
C12: 1000uF; CP_Elec_10x10
C13, C14: 220uF; CP_Elec_6.3x7.7
C18, C20: 20uF; C_1206_3216Metric_Pad1.33x1.80mm_HandSolder
C22: 43pF; C_0805_2012Metric_Pad1.18x1.45mm_HandSolder
C24: 1nF; C_0805_2012Metric_Pad1.18x1.45mm_HandSolder
D1: BZV55-B2V4.115; D_1206_3216Metric_Pad1.42x1.75mm_HandSolder
D2, D3, D5, D6: 1PS76SB40.115; D_SOD-323_HandSoldering
D4: LED_R; LED_1206_3216Metric_Pad1.42x1.75mm_HandSolder
F1, F2: MF-PPTC-1812-3.5A-6V; Fuse_1812_4532Metric_Pad1.30x3.40mm_HandSolder
F3: MF-PPTC-1812-2.6A-8V; Fuse_1812_4532Metric_Pad1.30x3.40mm_HandSolder
J1: USB_C_Receptacle_USB2.0; USB_C_Receptacle_Palconn_UTC16-G
J2: USB_B_Micro; USB_Micro-B_Amphenol_10103594-0001LF_Horizontal
J3: Screw_Terminal_01x02; TerminalBlock_Altech_AK300-2_P5.00mm
J4: Raspberry_Pi_2_3; raspberrypi_2_3
J5: USB_A; SAMTEC_USB-A-S-X-X-SM2
L1: 1uH; L_6.3x6.3_H3
L2: 1uH; L_10.4x10.4_H4.8
Q1, Q2, Q4, Q5, Q8: IRF7404; SOIC-8_3.9x4.9mm_P1.27mm
Q3, Q6, Q7, Q9: IRLML2803TRPBF; SOT95P237X112-3N; Manufacturer_Part_Number IRLML2803TRPBF; Mouser Part Number 942-IRLML2803TRPBF
R1, R2, R5, R14, R18, R19, R20, R22, R24, R29, R30, R31, R37, R40, R42, R43: 10k; R_0805_2012Metric_Pad1.20x1.40mm_HandSolder
R3, R4, R8, R9, R10, R12, R13, R16, R23, R25, R27, R35, R36, R38: 470; R_0805_2012Metric_Pad1.20x1.40mm_HandSolder
R6, R7, R17: 5.1k; R_0805_2012Metric_Pad1.20x1.40mm_HandSolder
R11: 100; R_0805_2012Metric_Pad1.20x1.40mm_HandSolder
R15: 1k; R_0805_2012Metric_Pad1.20x1.40mm_HandSolder
R21, R45, R46, R47, R48, R49: USR; R_0805_2012Metric_Pad1.20x1.40mm_HandSolder
R26: 64.9k; R_0805_2012Metric_Pad1.20x1.40mm_HandSolder
R28: 210k; R_0805_2012Metric_Pad1.20x1.40mm_HandSolder
R32: 18.7k; R_0805_2012Metric_Pad1.20x1.40mm_HandSolder
R33: 174k; R_0805_2012Metric_Pad1.20x1.40mm_HandSolder
R34: 147k; R_0805_2012Metric_Pad1.20x1.40mm_HandSolder
R39: 18k; R_0805_2012Metric_Pad1.20x1.40mm_HandSolder
R41: 200k; R_0805_2012Metric_Pad1.20x1.40mm_HandSolder
R44: 0; R_0805_2012Metric_Pad1.20x1.40mm_HandSolder
RT1: 10k; R_0603_1608Metric
SW1: SW_MEC_5E; SW_SPST_Omron_B3FS-100xP
SW2: MODE (JS102011SAQN); SW_SPDT_CK-JS102011SAQN
U1: LM393; SOIC-8_3.9x4.9mm_P1.27mm
U2: BQ25895RTW; Texas_S-PWQFN-N24_EP2.7x2.7mm_ThermalVias
U3: DW01; SOT-23-6
U4: FS8205A; TSSOP-8_4.4x3mm_P0.65mm
U5: TPS61088RHLR; IC_TPS61088RHLR; PARTREV 4219071/A 05/2017
U6: DS3231M; SOIC-16W_7.5x10.3mm_P1.27mm

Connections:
2V4: D1.1 (K), R3.1, R4.1, U1.2 (-), U1.6 (-)
+5V: C1.1, D5.2 (A), J1.A4 (VBUS), J1.A9 (VBUS), J1.B4 (VBUS), J1.B9 (VBUS), J2.1 (VBUS), Q1.5 (D), Q1.6 (D), Q1.7 (D), Q1.8 (D), R1.2, R16.2, U2.1 (VBUS)
+BATT: BT1.1 (+), C6.1, D6.2 (A), F1.2, F2.2, J3.1, R11.1, SW1.1, SW1.2, U2.13 (BAT), U2.14 (BAT)
GND: BT1.2 (-), C1.2, C5.2, C6.2, C9.1, C10.1, C11.1, C12.2, C13.2, C14.2, C15.2, C16.2, C18.2, C19.2, C20.2, C21.2, C22.2, C23.2, C24.2, D1.2 (A), J1.A1 (GND), J1.A12 (GND), J1.B1 (GND), J1.B12 (GND), J1.S1 (SHIELD), J2.5 (GND), J2.6 (Shield), J3.2, J4.6 (GND), J4.9 (GND), J4.14 (GND), J4.20 (GND), J4.25 (GND), J4.30 (GND), J4.34 (GND), J4.39 (GND), J5.4 (GND), J5.5 (Shield), Q3.2, Q6.2, Q7.2, Q9.2, R2.2, R6.2, R7.2, R20.2, R26.2, R29.1, R31.1, R34.1, R41.1, R46.1, R49.1, U1.4 (V-), U3.6 (GND), U4.2 (S1), U4.3 (S1), U5.12 (NC_12), U5.20 (AGND), U5.21 (PGND), U5.22 (PGND), U5.23 (PGND), U5.24 (PGND), U5.25 (PGND), U5.26 (PGND), U5.27 (PGND), U5.28 (PGND), U5.29 (PGND), U6.5 (GND), U6.6 (GND), U6.7 (GND), U6.8 (GND), U6.9 (GND), U6.10 (GND), U6.11 (GND), U6.12 (GND), U6.13 (GND); also elsewhere on the board
GND1: C3.2, C4.2, C7.1, R12.2, R15.1, R18.1, R19.1, RT1.1, U2.8 (OTG), U2.17 (PGND), U2.18 (PGND), U2.25 (PGND), U4.6 (S2), U4.7 (S2)
INT: R43.1, R44.2, U2.7 (INT)
unnamed: C2.1, L1.1, U2.19 (SW), U2.20 (SW)
unnamed: C2.2, U2.21 (BTST)
unnamed: C4.1, U2.23 (PMID)
unnamed: C5.1, R11.2, U3.5 (VCC)
unnamed: C7.2, R14.2, U2.22 (REGN)
unnamed: C8.1, Q4.1 (S), Q4.2 (S), Q4.3 (S), Q5.1 (S), Q5.2 (S), Q5.3 (S), R22.2
unnamed: C8.2, Q4.4 (G), Q5.4 (G), R22.1, R23.2
unnamed: C17.1, Q7.1, R27.2, R29.2
unnamed: C17.2, R1.1, R2.1, U1.3 (+)
unnamed: C18.1, C19.1, C20.1, L2.2, Q8.5 (D), Q8.6 (D), Q8.7 (D), Q8.8 (D), R37.2, R39.2, U5.9 (VIN)
unnamed: C21.1, U5.1 (VCC)
unnamed: C22.1, R32.2, U5.18 (COMP)
unnamed: C23.1, U5.10 (SS)
unnamed: C24.1, R32.1
unnamed: C25.1, L2.1, R33.1, U5.4 (SW_7), U5.5 (SW_4), U5.6 (SW_5), U5.7 (SW_6)
unnamed: C25.2, U5.8 (BOOT)
unnamed: D2.1 (K), U3.3 (OC), U4.5 (G2)
unnamed: D2.2 (A), D3.2 (A), R16.1
unnamed: D3.1 (K), U3.1 (OD), U4.4 (G1)
unnamed: D4.1 (K), U2.4 (STAT)
unnamed: D4.2 (A), R17.2
unnamed: D5.1 (K), R36.1
unnamed: D6.1 (K), U6.14 (VBAT)
unnamed: F1.1, F2.1, Q8.1 (S), Q8.2 (S), Q8.3 (S), R30.1
unnamed 30: F3.2, J5.1 (VBUS), R45.2, R48.2; also elsewhere on the board
unnamed: J1.A5 (CC1), R6.1
unnamed: J1.B5 (CC2), R7.1
unnamed: J2.2 (D-), R21.2
unnamed: J2.3 (D+), R21.1
unnamed: J4.7 (GCLK0/GPIO4), R44.1
unnamed: J5.2 (D-), R47.2, R48.1, R49.2
unnamed: J5.3 (D+), R45.1, R46.2, R47.1
unnamed: Q1.1 (S), Q1.2 (S), Q1.3 (S), Q2.1 (S), Q2.2 (S), Q2.3 (S), R5.2
unnamed: Q1.4 (G), Q2.4 (G), R5.1, R10.2
unnamed: Q3.1, R13.2, R20.1
unnamed: Q3.3, R10.1
unnamed: Q6.1, R24.1, R25.2
unnamed: Q6.3, R23.1
unnamed: Q7.3, R25.1
unnamed: Q8.4 (G), Q9.3, R30.2
unnamed: Q9.1, SW2.2 (B)
unnamed: R9.1, U2.10 (ILIM)
unnamed: R9.2, R12.1
unnamed: R8.1, R13.1, R27.1, U1.1
unnamed: R14.1, R19.2, RT1.2, U2.11 (TS)
unnamed: R15.2, U3.2 (CS)
unnamed: R18.2, U2.9 (~CE)
unnamed: R26.1, R28.2, U5.17 (FB)
unnamed: R31.2, SW2.3 (C)
unnamed: R33.2, U5.3 (FSW)
unnamed: R34.2, U5.19 (ILIM)
unnamed: R35.1, R36.2, R37.1, R38.2, SW2.1 (A)
unnamed: R35.2, SW1.3 (K), SW1.4 (A)
unnamed: R38.1, U1.7
unnamed: R39.1, R41.2, U1.5 (+)
unnamed: U2.2 (D+), U2.3 (D-)
Pi_3v3: J4.1 (3V3), R40.2, R42.2, R43.2, U6.2 (VCC)
SCL: J4.5 (SCL/GPIO3), R42.1, U2.5 (SCL), U6.16 (SCL)
SDA: J4.3 (SDA/GPIO2), R40.1, U2.6 (SDA), U6.15 (SDA)
VOUT: C9.2, C10.2, C11.2, Q4.5 (D), Q4.6 (D), Q4.7 (D), Q4.8 (D), R3.2, R4.2, R8.2, R24.2, R28.1, U1.8 (V+), U5.14 (VOUT_16), U5.15 (VOUT_14), U5.16 (VOUT_15)
VSYS: C3.1, L1.2, R17.1, U2.15 (SYS), U2.16 (SYS), U5.2 (EN)
V_UPS: C12.1, C13.1, C14.1, C15.1, C16.1, F3.1, J4.2 (5V), J4.4 (5V), Q2.5 (D), Q2.6 (D), Q2.7 (D), Q2.8 (D), Q5.5 (D), Q5.6 (D), Q5.7 (D), Q5.8 (D)

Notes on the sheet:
Enable without input voltage
Battery chrage/managment unit
Ports and outputs + RTC
5V Booster circuit
Calculate later
(200k)
(18k)
Power MUX
Pull this up to VSYS?
(62k)
B57351V5103H060
SMDCAP-220mkf - 6,3v (105 С) SMD (RC) 6,3*7,7
100 works

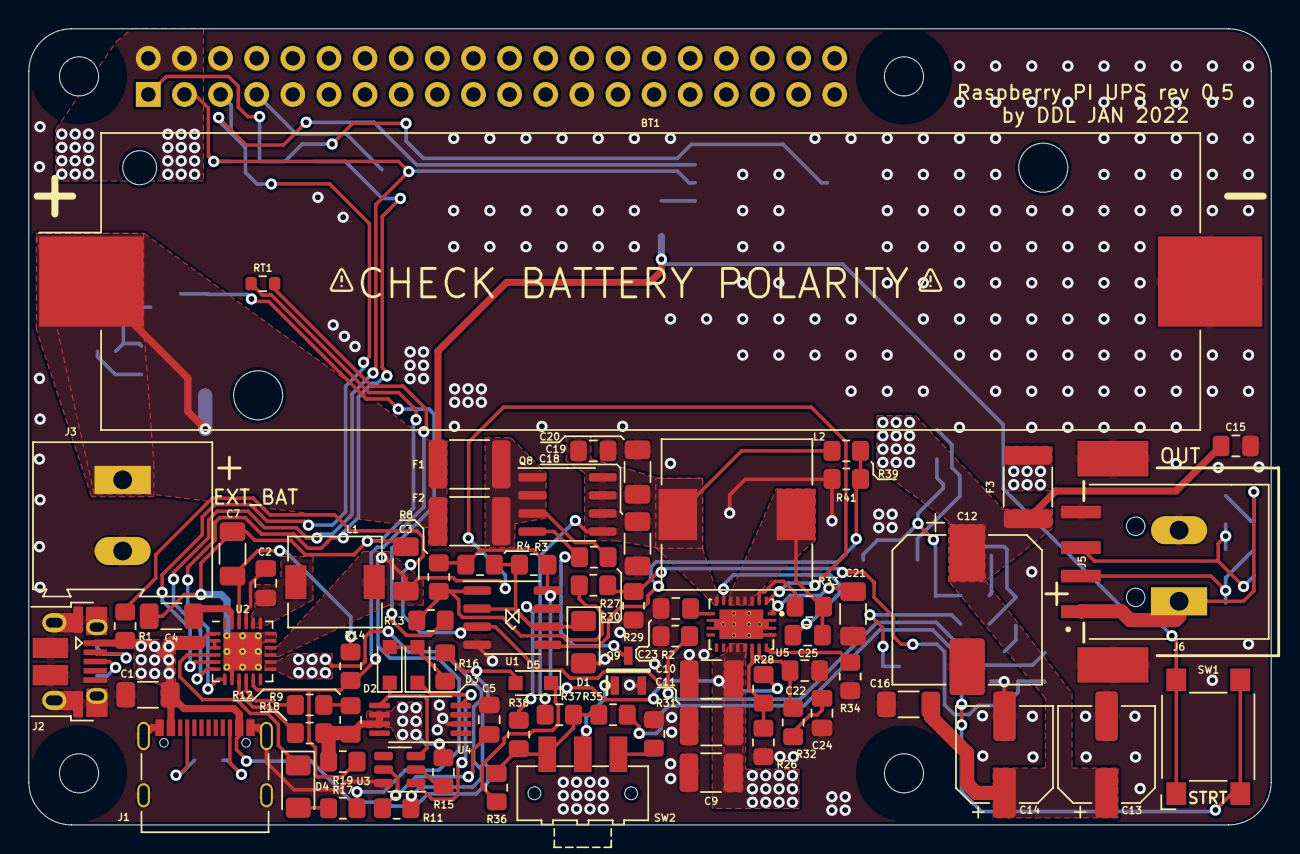
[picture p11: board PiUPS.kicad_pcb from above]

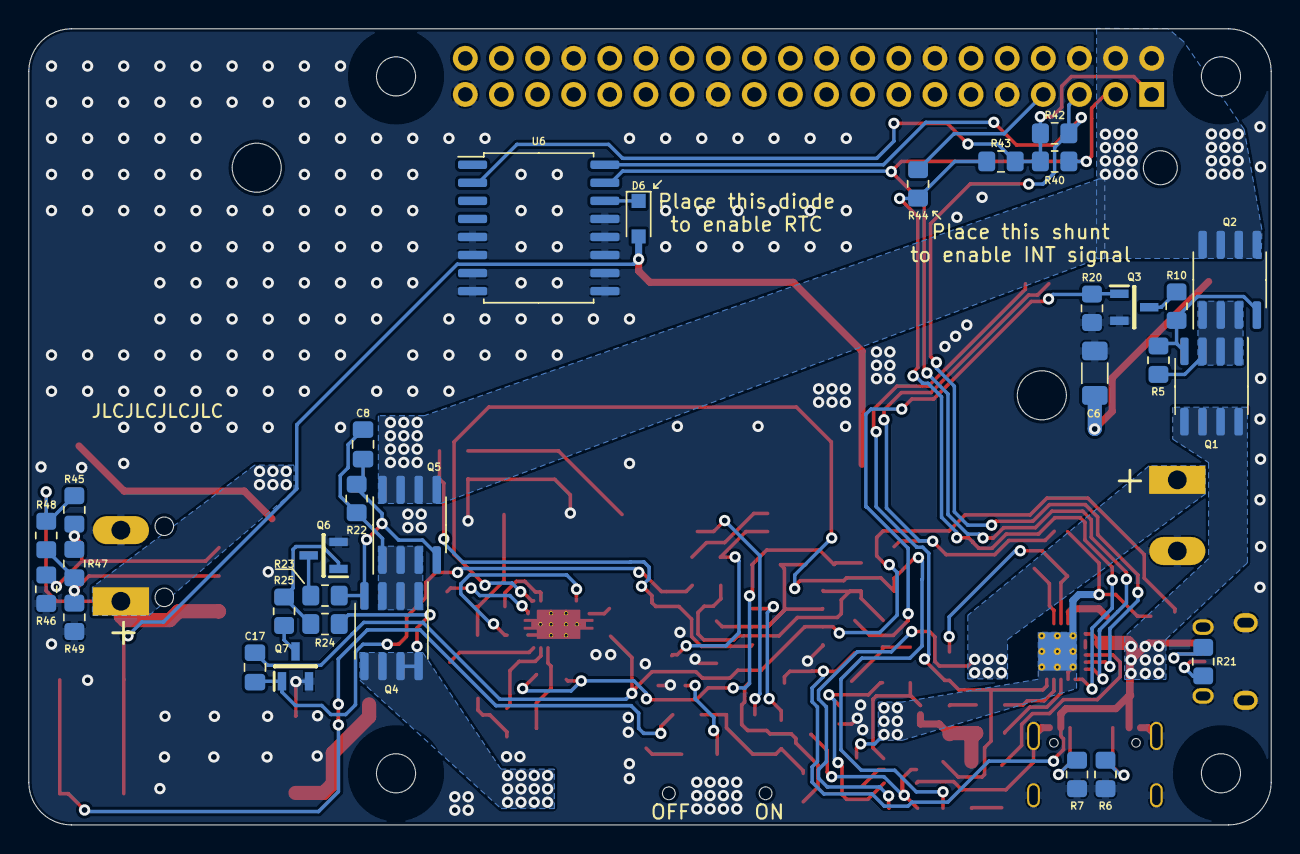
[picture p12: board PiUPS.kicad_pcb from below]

Board: 2 copper layers, 87.4 x 56.0 mm, 110 parts (31 on the bottom side), 68 nets.

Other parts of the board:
J6: Screw_Terminal_01x02; TerminalBlock_Altech_AK300-2_P5.00mm

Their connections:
GND: J6.2; also elsewhere on the board
unnamed 30: J6.1; also elsewhere on the board

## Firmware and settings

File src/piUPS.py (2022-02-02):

import smbus2 as sm

class PiUPS:

    # IC reference https://www.ti.com/lit/ds/symlink/bq25601.pdf




    # Select target charging current (only one)

    # CHG_LIM = 0b00000000 # 100mA
    # CHG_LIM = 0b00000001 # 200mA
    # CHG_LIM = 0b00000010 # 300mA
    # CHG_LIM = 0b00000011 # 400mA
    CHG_LIM = 0b00000100 # 500mA
    # CHG_LIM = 0b00000101 # 600mA
    # CHG_LIM = 0b00001001 # 1A
    # CHG_LIM = 0b00001110 # 1.5A
    # CHG_LIM = 0b00010100 # 2A
    # CHG_LIM = 0b00010111 # 2.4A
    # CHG_LIM = 0b00011111 # 3.2A MAX




    # Select target battery voltage for charging (select one)

    # VBAT_MAX = 0b00000000 # 3.856V
    # VBAT_MAX = 0b00000100 # 3.984V
    # VBAT_MAX = 0b00000110 # 4.048V
    # VBAT_MAX = 0b00001000 # 4.112V
    VBAT_MAX = 0b00001011 # 4.208V


    # Select shutdown voltage (one)
    # VSYS_MIN = 0b00000010 # 3 V
    # VSYS_MIN = 0b00000011 # 3.2 V
    # VSYS_MIN = 0b00000100 # 3.4 V
    VSYS_MIN = 0b00000101 # 3.5 V (default)
    # VSYS_MIN = 0b00000110 # 3.6 V
    # VSYS_MIN = 0b00000111 # 3.7 V
    
    # Internal vars:

    I2C_ADDR = 0x6B

    CHG_ADDR = 0x00
    VBMAX_ADDR = 0x04
    VSMIN_ADDR = 0x01
    VSYS_STAT_ADDR = 0x08
    BATEFET_ADDR = 0x07

    BATFET_TIMER = 0b00010000
    BATFET_TURN_OFF = 0b00000100 

    

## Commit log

2021-08-07 initial commit
    First upload
    [PiUPS-B_Cu.gbr, PiUPS-B_Mask.gbr, PiUPS-B_Paste.gbr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]
2021-09-18 Updated to include the boges to rev 0.2
    [PiUPS-B_Cu.gbr, PiUPS-B_Mask.gbr, PiUPS-B_Paste.gbr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]
2022-02-02 rev 0.5 update (#2)
    * added exprimental latching boost IC cutoff circuit + notes about dev branch file and future things to do
    * updated debug schematic
    * added almost final fixes for rev 0.1
    * tidied up schematic
    * updated to Kicad 6.0
    * minor improvements and cleanup
    * added label on PCB to indicate that it is outdated
    * minor changes
    * assigned footprints
    * beginning of routing
    * Continued routing
    * continued routing
    * almost finished routing
    * finshed layout and routing
    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
    [PiUPS-B_Cu.gbl, PiUPS-B_Mask.gbs, PiUPS-B_Paste.gbp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]
2022-02-02 Fixed DRC issues
    [PiUPS.kicad_pcb]
2022-02-02 added new gerbers
    [PiUPS-B_Cu.gbl, PiUPS-B_Mask.gbs, PiUPS-B_Paste.gbp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]
2022-04-27 minor touchups
    [PiUPS.kicad_pcb]
2022-05-10 minour improvements
    [PiUPS-B_Cu.gbl, PiUPS-B_Mask.gbs, PiUPS-B_Paste.gbp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]
2022-07-07 updated development schematic
    [PiUPS.kicad_sch]
2022-07-18 updated components and schematic sligtly
    [PiUPS.kicad_sch]
2022-09-15 updated shcematic with new battery protection system and some notes
    [PiUPS.kicad_sch]
2022-09-18 changed some values
    [PiUPS.kicad_sch]
2022-09-22 working on fixing some design mistakes
    [PiUPS.kicad_sch]
2022-11-06 added possible comparator replacement schematics
2023-02-09 minor changes
    [PiUPS.kicad_sch]
2023-04-29 minor schematic changes
    [PiUPS.kicad_sch]
